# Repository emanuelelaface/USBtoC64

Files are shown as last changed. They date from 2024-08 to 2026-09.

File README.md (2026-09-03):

# USB Adapter for Commodore 64, AMIGA and ATARI Joystick and Mouse Port

This adapter interfaces a USB device with the CONTROL Port of the C64, AMIGA and ATARI, allowing it to be used as a mouse or joystick.

The joystick connects via pins 1, 2, 3, 4, and 6 of the CONTROL port, with the GPIOs simply set as open circuits or shorted to ground when a joystick direction is pressed.

On the C64, the mouse uses the analog part of the port (Pot X and Pot Y). The Commodore 64 has these two pins for evaluating an analog resistor that charges an internal capacitor. The charging time is decoded as a resistor value with a digital value from 0 to 255. The trick used by Commodore engineers to use it as a mouse was to send a pulse at the right moment, making the C64 believe that the capacitor is fully charged. To establish the right moment, the C64 goes through 512 cycles (almost 512 microseconds, since the clock frequencies of PAL and NTSC are not exactly 1 MHz: PAL is 0.985248 MHz, NTSC is 1.022727 MHz). During the first 256 cycles, the potentiometer is set to ground, then it charges the capacitor.

The idea is to use an ESP32 board to wait for the discharge drop and then an additional 256 cycles, finally sending the proper value to the C64 at the right moment. The ESP32 allows interrupts when an input signal is falling; however, the voltage from the C64 is a bit too low for the ESP32 interrupt because the board requires at least 3 volts, while the C64 provides around 1.2 volts. Therefore, a BJT is used to amplify the signal (and invert it, so it is HIGH when the C64 is LOW, which reduces noise in detecting the status).

The initial variable values are the timing for a PAL C64 and are obtained empirically. The NTSC version of the timings are calculated scaling for the ratio of the frequencies NTSC/PAL. It is possible that another C64 may use slightly different timing, though it should be quite stable since Commodore sold the same mouse to everyone. When I will have one NTSC Commodore, I will test it and adjust the timings if needed.

On AMIGA and ATARI the mouse is encoded in the quadrature signal using two trains of pulses with 90 degrees of shift in order to identify the steps and the directions of the motion.

There is an additional switch to make the board work in mouse mode or joystick mode. In mouse mode, any connected device will use the analog mouse, so a program like GEOS can be controlled with a USB mouse or a gamepad. In joystick mode, the board uses the joystick pins for any kind of device. This means that some games, like graphic adventure games (e.g., Maniac Mansion), can be played with a mouse even if they were originally designed for a game controller.

The target computer selection (C64 / AMIGA / ATARI) is user-selectable and stored in non-volatile memory, so it persists across reboots. To change it you must connect a USB mouse to the adapter, turn on the computer and, within the first 30 seconds from the boot, press and hold one mouse button for about 5 seconds until the LED blinks. The button you hold selects the target machine:
- **Left button**: Commodore 64
- **Right button**: AMIGA
- **Middle button**: ATARI

After the LED blink feedback, the adapter reboots and returns to the normal LED behavior (mouse mode or joystick mode depending on the switch position).

The PCB are in two versions: THT (version 3.2) and SMD (version 4.1). The functionalities are identical.

<p align="center">
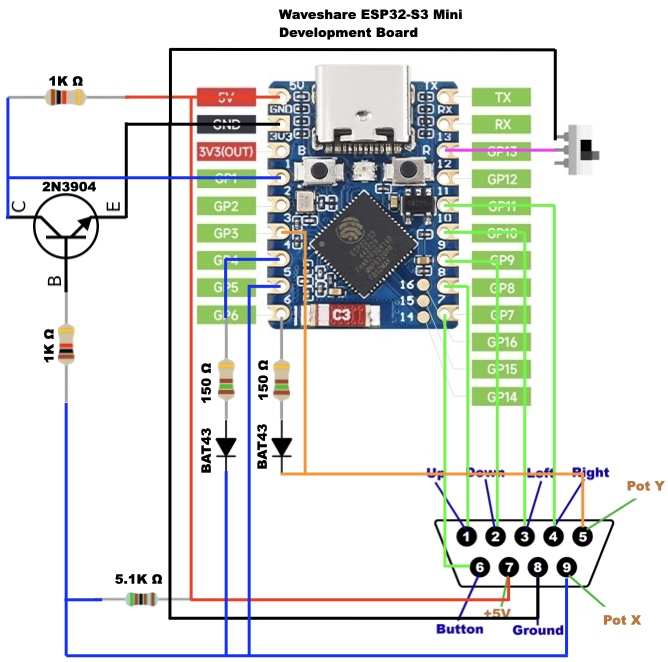
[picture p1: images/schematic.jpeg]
Schematic
  
</p>

<div style="display: flex; justify-content: space-between;">
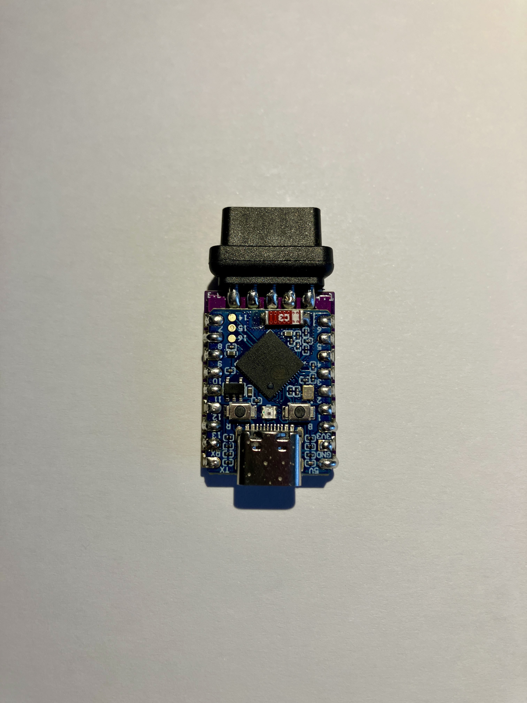
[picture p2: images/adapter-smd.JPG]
SMD
  
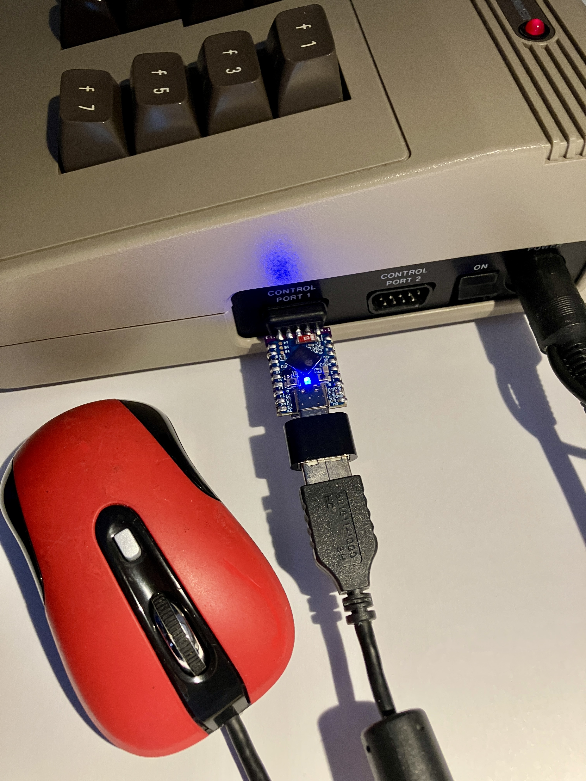
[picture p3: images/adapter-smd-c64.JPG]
SMD C64
  
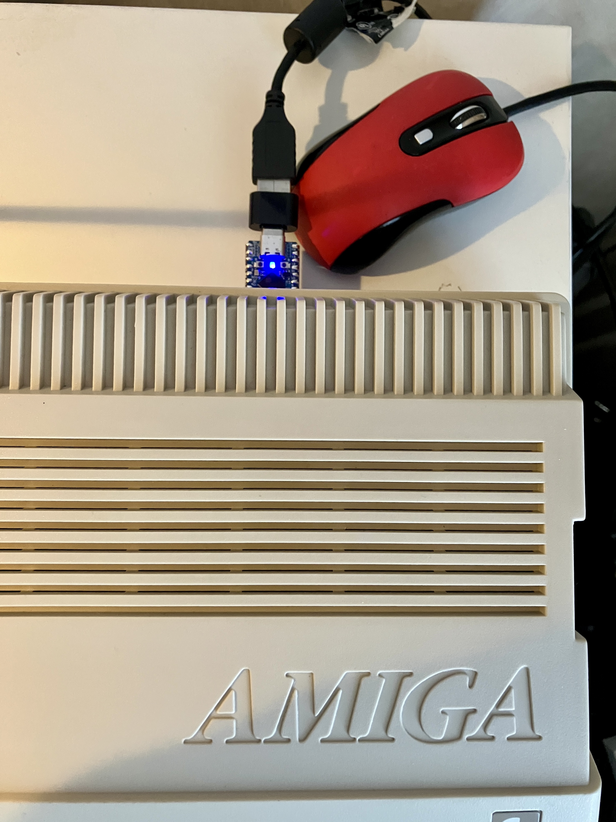
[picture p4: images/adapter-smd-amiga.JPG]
SMD Amiga
  
</div>

<div style="display: flex; justify-content: space-between;">
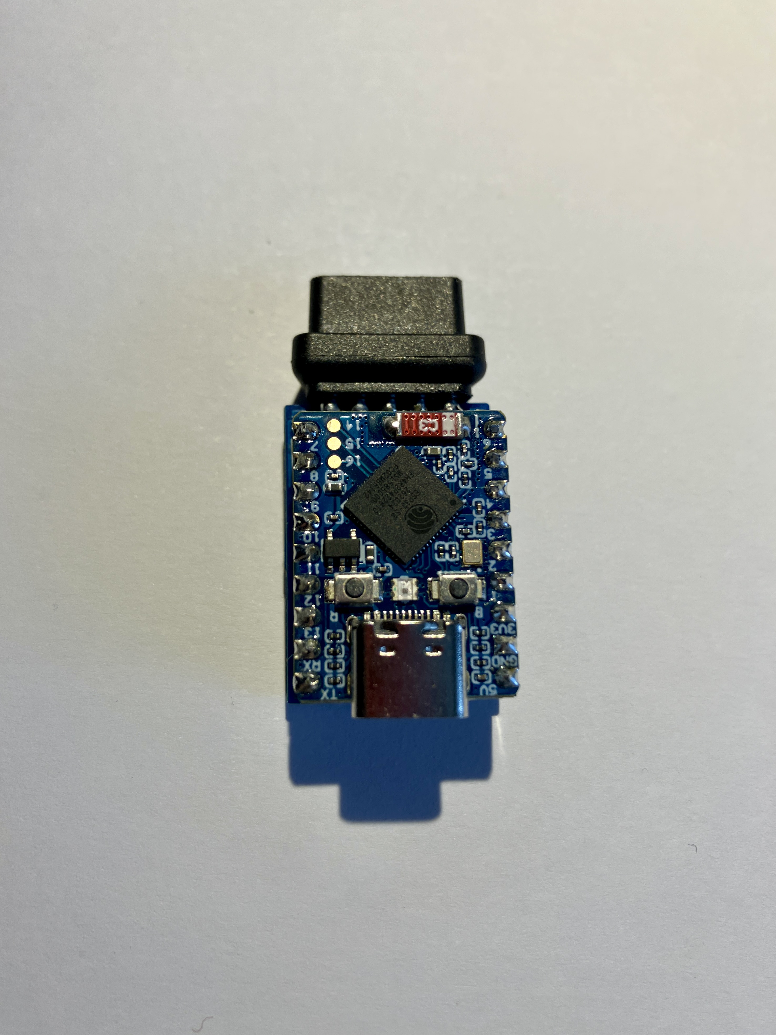
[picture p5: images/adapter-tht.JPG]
THT
  
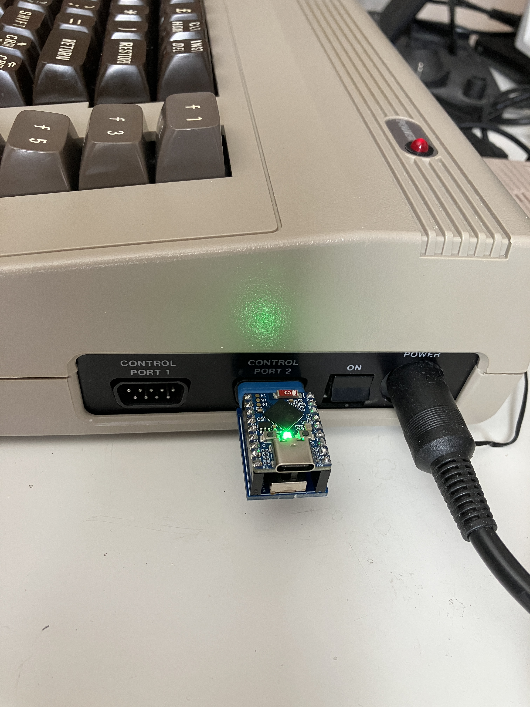
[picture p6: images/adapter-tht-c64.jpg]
THT C64
  
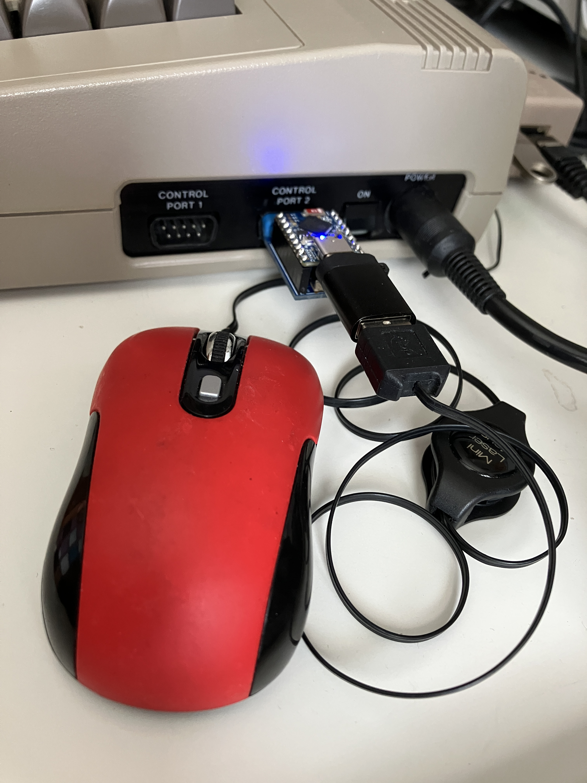
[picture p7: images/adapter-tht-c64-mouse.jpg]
THT C64 Mouse
  
</div>

## Pre-assembled and Tested Board

<div style="display: flex; justify-content: space-between;">
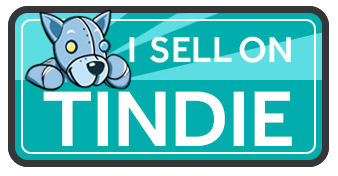
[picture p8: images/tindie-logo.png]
Tindie Logo Link
  
</div>

If you like this project and want a fully assembled and tested board, you can purchase it on [Tindie](https://www.tindie.com/products/burglar_ot/usb-to-commodore-64-amiga-atari/). By doing so, you can also benefit from a customized configuration and support the future development of the project.

## Components

- **ESP32 S3 Mini**: I use the [Waveshare](https://www.waveshare.com/esp32-s3-zero.htm) version. There are other boards with a similar form factor, but the pinout may be different, which would require redesigning the board.
- **2N3904 NPN transistor**.
- **PCB Slide Switch, 3-pin**.
- **Two 1 kOhm resistors, 1% tolerance**.
- **Two 150 Ohm resistors, 1% tolerance**.
- **One 5.1 kOhm resistor, 1% tolerance**.
- **Two BAT 43 Schottky Diodes**.
- **DE-9 (also known as D-SUB 9 or DB 9) female connector**: It's good practice to remove the metallic enclosure because it can easily short the +5V line of the C64 when inserted, potentially damaging your computer.

---

## Installation From Arduino IDE

To install the code from the source file **USBtoC64.ino**, you will need the Arduino IDE. Ensure that the ESP32 board is installed, specifically the ESP32S3 Dev Module.  
The flag `PAL` is for C64 PAL / NTSC selection.

Additionally, the ESP32 USB HID HOST library is required. This library is not available in the official repository. You can download the ZIP file of the repository from [ESP32_USB_Host_HID](https://github.com/esp32beans/ESP32_USB_Host_HID). To install it, go to `Sketch -> Include Library -> Add .ZIP Library` in the Arduino IDE.

To set the board in upload mode, hold the **BOOT** button while the board is disconnected from the USB port. Then, connect the board to the USB port and after one second, the USB port should appear in the list of ports in the Arduino IDE. You can then upload the code.

To select PAL or NTSC timing the `#define PAL` line has to be set as true or false.

## Installation From the Binary File

Alternatively, you can load the binary file **USBtoC64-AMIGA-ATARI-PAL.bin** or **USBtoC64-AMIGA-ATARI-NTSC.bin**, which are located in the `BIN` folder.
The tool to upload the binary is `esptool`. This is available as a web page or as python. The web page should be compatible with Chrome browser or similar, probably not with Firefox, but on some operating system (like Mac OS) there can be a problem of binding the port to the web page. Anyway my suggestion is to try the web page first because it is very fast, and if it does not work try with the python installation.

### From the web page

1. Disconnect the adapter from the Commodore 64 / AMIGA / ATARI.
2. Press and hold the **BOOT** button before connecting the board to the USB cable on the computer. Then, connect the board, wait a second, and release the button.
3. Go to the [esptool](https://espressif.github.io/esptool-js/) website, click on **Connect**, select the port for your adapter, change the Flash Address into `0x0000` and upload the firmware.

### From Python

1. Install the esptool with `pip install esptool`.
2. Disconnect the adapter from the Commodore 64.
3. Press and hold the **BOOT** button before connecting the board to the USB cable on the computer. Then, connect the board, wait a second, and release the button.
4. On the computer, run:

   `esptool.py -b 921600 -c esp32s3 -p <PORT> write_flash --flash_freq 80m 0x00000 USBtoC64-<PAL|NTSC>.bin`

   where `<PORT>` is the USB port created once the board is connected. On Windows, it is probably COM3 or something similar. On Linux and Mac, it will be `/dev/tty.USBsomething` or `/dev/cu.usbsomething`. `<PAL|NTSC>` is the version with the timings for PAL or for NTSC version of the Commodore 64.

---

## Joystick Configuration

Each joystick or gamepad presents data to the USB in a different way. The library used for ESP32 receives an array of `uint8_t` where each element of the array is connected to a button or an axis, and it is not possible to predict in advance how the joystick will associate this data to the buttons. Therefore, the user has to configure the USBtoC64 manually. To do this, follow the procedure below:

- Identify the **BOOT** button on the board. It is the left button when the USB port is oriented towards the top.
- Disconnect the joystick from the controller.
- When the controller is connected to the Commodore 64, it will boot with a `RED` LED for one second, then it will change to green (for Joystick) or blue (for mouse) depending on the position of the switch mode.
- To set the controller in configuration mode, the **BOOT** button must be pressed during the red light. This can be done by rebooting the board (pressing the other button on the board, which is the reset button) and then holding the **BOOT** button during the red LED.
- If pressed correctly, the red light will flash 10 times quickly, and then a `GREEN` LED will indicate that the board is in configuration mode.
- Insert the USB controller to configure; the green light should turn off, and the controller is ready to be programmed.
- The procedure now requires the insertion of 7 controls: the 4 directions in the exact sequence **UP, DOWN, LEFT, RIGHT**, and then 3 buttons for **FIRE**. (3 because most controllers have many buttons and it can be useful to map more than one to fire. Additionally, when the joystick is used in mouse mode, the first 2 fire buttons are assigned as left and right buttons.)
- To associate the controls, press the **BOOT** button each time and then the controller direction.
- Press the **BOOT** button; a `BLUE` LED should appear, and the controller will wait for the UP direction. Once the UP direction is pressed on the controller, the blue LED will turn off.
- Repeat the previous step for DOWN, LEFT, RIGHT, FIRE1, FIRE2, FIRE3.
- After the last button, the controller will flash a `GREEN` LED and will be set to work with that controller.
- It is now possible to reboot the controller and use it with the configured joystick.

If your controller is advanced, with analog joystick and you want to map specifically as mouse or you want some more advanced customization you can discover how your values are mapped following this [Configurator](https://raw.githack.com/emanuelelaface/USBtoC64/main/configurator/config.html) (it works on Chrome and similar browsers, not on Firefox) and once you download the JoystickMapping file you can contact me for a specific configuration, or if you know your business you can code your controls directly in the firmware source replacing the example JoystickMapping.h file and upload to your controller.

---

## Mouse Wheel Support (C64OS + AmigaOS)

An additional **MouseMapping.h** is available to support the **mouse wheel (scroll)** on both **C64OS** and **AmigaOS**.
In order to activate it in the code the variable **MOUSE_MAP_CUSTOM** must be set to **1** and the proper mouse mapping has to be added in the **MM_REPORT_MAPS**. This requires to know how the bytes of the mouse are mapped, I am working on a procedure to get this authomatically in the future.

### C64OS (Wheel Support)
- Requires **C64OS version 1.03 or newer**.
- In the **Mouse** settings/menu, select the **Micromys** driver.

### AmigaOS (Wheel Support)
- Install [FreeWheel](https://aminet.net/package/util/mouse/FreeWheel) on your Amiga.
- Open **FreeWheel** settings, go to **Set Buttons**, and set the **Middle button** to enable scrolling.

---

WARNING: Some controllers may use the USB port to charge a battery (especially if they are also Bluetooth), and this could draw more than 100 mA from the C64, potentially shutting down the Commodore (and possibly damaging it). If you use a controller with a battery, you should remove the battery before connecting it or disable the charging functionality if possible.

---

WARNING: DON'T CONNECT THE COMMODORE 64 AND THE USB PORT TO A SOURCE OF POWER AT THE SAME TIME.  
THE POWER WILL ARRIVE DIRECTLY TO THE SID OF THE COMMODORE AND MAY DESTROY IT.

---

THE SOFTWARE IS PROVIDED “AS IS”, WITHOUT WARRANTY OF ANY KIND, EXPRESS OR IMPLIED, INCLUDING BUT NOT LIMITED TO THE WARRANTIES OF MERCHANTABILITY, FITNESS FOR A PARTICULAR PURPOSE AND NONINFRINGEMENT. IN NO EVENT SHALL THE AUTHORS OR COPYRIGHT HOLDERS BE LIABLE FOR ANY CLAIM, DAMAGES OR OTHER LIABILITY, WHETHER IN AN ACTION OF CONTRACT, TORT OR OTHERWISE, ARISING FROM, OUT OF OR IN CONNECTION WITH THE SOFTWARE OR THE USE OR OTHER DEALINGS IN THE SOFTWARE.

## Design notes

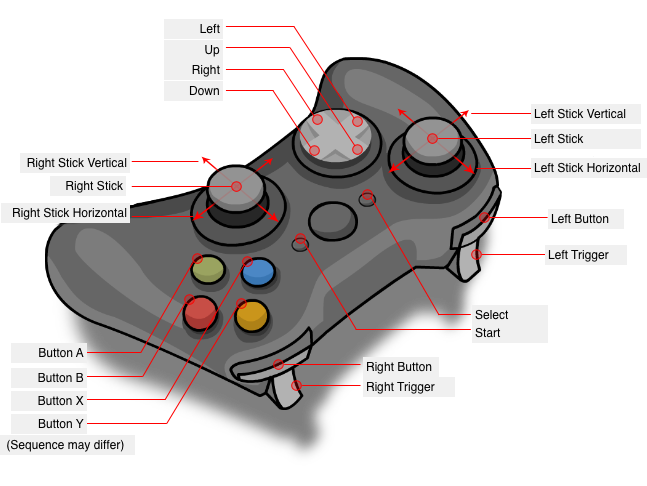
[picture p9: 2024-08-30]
images/gamepad.png

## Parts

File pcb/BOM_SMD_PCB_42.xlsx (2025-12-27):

Designator | Footprint | JLCPCB Part # | Quantity | Description | Manufacturer | Comment | Value
D1 | 2N3904 | C18536 | 1 | 100@10mA,1V 200mA 300MHz 300mV 350mW 40V NPN SOT-23 Bipolar (BJT) ROHS | KEC Semicon | NPN transistor
D2 | PCB Slide Switch, 3-pin | C259308 | 1 | -25℃~+80℃ 1.5mm 10,000 Cycles 300mA 3mm 6V 7mm Black Gull Wing Rectangular Columnar SPDT Surface Mount, Right Angle SMD,7x3mm Slide Switches ROHS | Korean Hroparts Elec
D3,D4 | 1 kOhm resistors | C17513 | 2 | -55℃~+155℃ 125mW 150V 1kΩ Thick Film Resistor ±1% ±100ppm/℃ 0805 Chip Resistor - Surface Mount ROHS | UNI-ROYAL(Uniroyal Elec)
D5,D6 | 150 Ohm resistors | C17471 | 2 | -55℃~+155℃ 125mW 150V 150Ω Thick Film Resistor ±1% ±100ppm/℃ 0805 Chip Resistor - Surface Mount ROHS | UNI-ROYAL(Uniroyal Elec)
D7 | 5.1 kOhm resistor | C26023 | 1 | -55℃~+155℃ 125mW 150V 5.1kΩ Thick Film Resistor ±100ppm/℃ ±5% 0805 Chip Resistor - Surface Mount ROHS | UNI-ROYAL(Uniroyal Elec)
D8,D9 | BAT 43 Schottky Diodes | C22466358 | 2 | -40℃~+125℃ 200mA 30V 450mV@15mA 4A 500nA@25V Independent SOD-123 Schottky Diodes ROHS | hongjiacheng

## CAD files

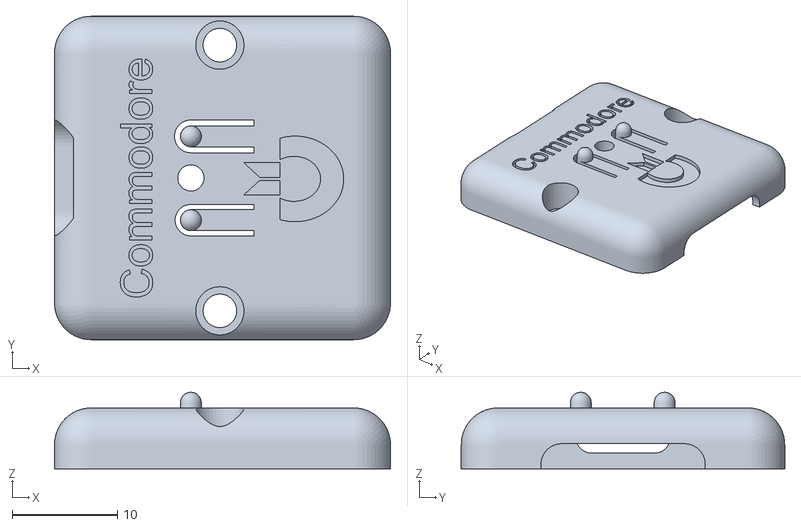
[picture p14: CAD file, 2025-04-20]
3Dcase/SMD/top.stl
32.0 x 30.8 x 7.30

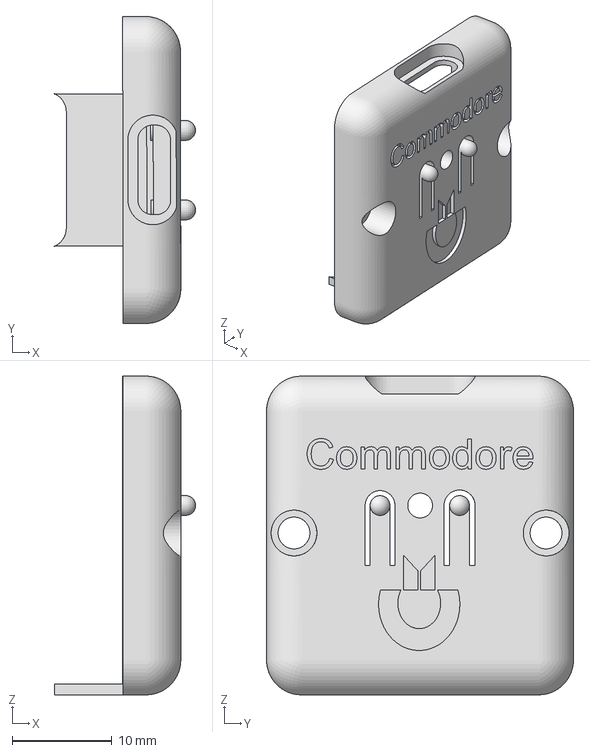
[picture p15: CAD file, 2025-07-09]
3Dcase/THT/top.3mf
14.2 x 30.8 x 32.0 mm

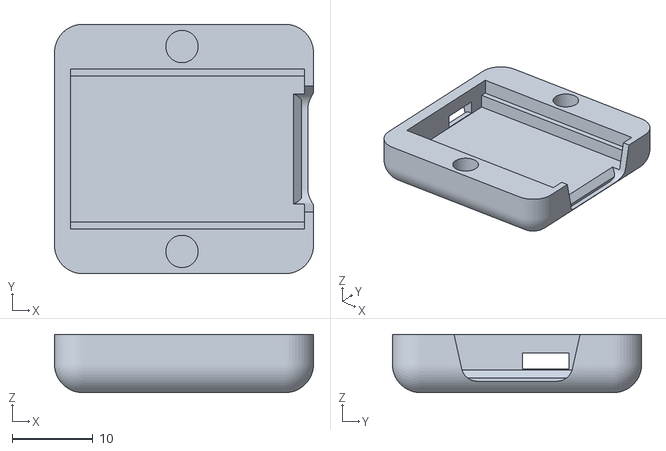
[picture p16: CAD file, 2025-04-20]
3Dcase/SMD/bottom.stl
32.0 x 30.8 x 7.20

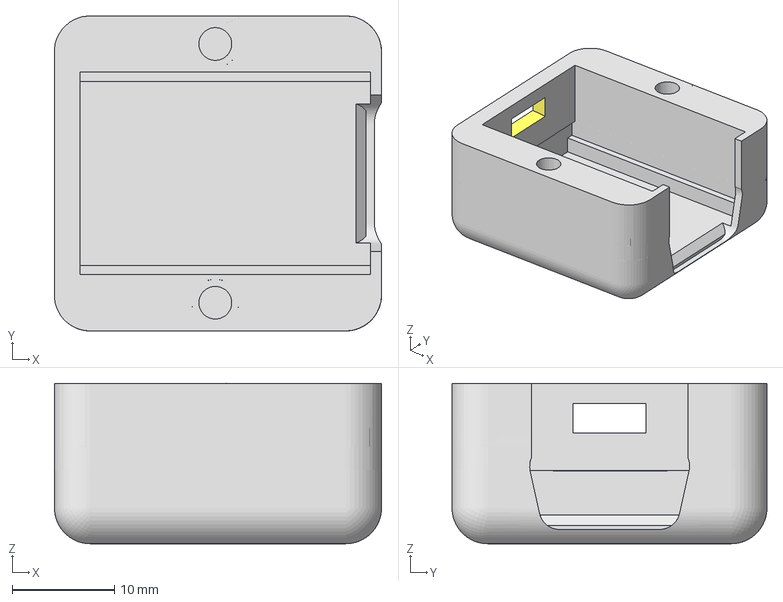
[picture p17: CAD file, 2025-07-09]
3Dcase/THT/bottom.3mf
32.0 x 30.8 x 15.7 mm

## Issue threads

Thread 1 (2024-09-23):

Never leaves configuration mode.

chris-edwards-pub, 2024-09-23:
I booted into configuration mode, then insert mouses USB and the green light just stays on.  Never turns off.  Any ideas?

emanuelelaface, 2024-09-23:
hi, so if I understood correctly, you started the board, when there is the red light you hold the B button, the red led flashes and then you have the green led on. Now you insert the USB joystick/gamepad and nothing happens, am I right?

chris-edwards-pub, 2024-09-23:
Thanks!  I was trying to configure the mouse.  BTW, the mouse work perfect.

emanuelelaface, 2024-09-23:
perfect, thanks for the check!

Closed 2024-09-23.

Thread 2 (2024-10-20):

Mouse not recognized using BackSID

doughamm, 2024-10-20:
Using a BackSID, the pots won't register. BackSID is one of the few SID replacements that emulates pots but others that do may have problems as well.  BackSID works with MouSTer just fine but not USBtoC64.

emanuelelaface, 2024-10-20:
Hi, at the time I developed this device I had a C64 with an original SID that produces the timing signal for the POTS all the time, and I created the project around that. Then a user reported the issue with ARMSID and I discovered that those clones do not generate the signal unless there is some voltage applied to the pot. So I fixed the design but I still have few adaptors from the previous design that are compatible only with the original SID. This is why on the site where I sell them I ask specifically to say if the user wants to use with a clone SID in order to send a modified version that is compatible with it.

By the way, I tested it with ARMSID and SIDKick, not with BackSID (I do not have one) but I guess it will work also with it because I think the only problem is to enable the digital generation of the signal on the POT pins.

Said this, please contact me on the place where you bought the adapter and I will try to fix this issue for you.

doughamm, 2024-10-20:
Ah, I totally see now this option on the Tindy site that either didn't exist or I hadn't noticed back in September when I ordered!

https://www.tindie.com/products/burglar_ot/usbtoc64/

About half my systems are BackSID while the rest are authentic; does the revised board retain compatibility with authentic SIDs or do you essentially need a board for each scenario?

In any case I would love to acquire the revised one. Happy to do so however is most convenient.

Thank you!

emanuelelaface, 2024-10-20:
Yes the other revision works with every system, but maybe you can modify your without order a new one. I will write you from Whatsapp if you don't mind, on the number provided on Tindie.

doughamm, 2024-10-26:
Just updating the issues log to echo my WhatsApp discussion for the greater community: adding a resistor gets it to recognize a mouse on the BackSID, and it does move, but it's unusably jumpy (whether a mouse is connected or not).  I've also let Evie know on her forum since this may be a firmware-solvable issue as much as a hardware one: https://forum.backbit.io/index.php?topic=1218.0

emanuelelaface, 2024-11-22:
I will close here. I think the issue with BackSID is possibly due to the voltage expected buy the replacement SID or something else. I cannot test it in my lab because I do not have one and to do a full debug I need to see the signals with an oscilloscope. I had the possibility to test it with ARMSID and SIDKick, both work fine, but BackSID probably needs +5v as HIGH signal while the ESP32 board uses +3.3v.

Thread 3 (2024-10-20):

Gamepad compatibility list?

doughamm, 2024-10-20:
Unsure if this should be here, but it would be useful to know what pads and sticks are tested as working and which should not be used for safety reasons. Thanks!

emanuelelaface, 2024-10-20:
I am not sure that it is an issue, but it is fine to have it here.
So far the gamepad used by the users are many and some of them is not even commercial but custom made and all of them worked fine. For some of them I had to create a specific firmware, but none of them had issues with the commodore.
My disclaimer is because I discovered that the 8bitdo pro 2 (my controller) charges the battery from the USB and this absorbs more power than the one provided by the Commodore, and when this happens the Commodore shuts down (probably not very healthy). The problem is easily fixable removing the battery from the controller when used with the C64.

Any other controller (I had reports from dozens of users) are perfectly fine, even for non-commercial devices.
If you have a specific controller that you want to use you may try to contact me directly (from the site where you bought it) and I can help you with a custom firmware for your game controller, or I can check if some other user reported it as safe (but I am quite sure that it is most of the time).

doughamm, 2024-10-20:
Thank you! I attempted to try an Xbox One controller over micro USB seeing as it has no battery and would be safe. Didn't seem to work, but I'll give it another shot if you suggest it ought to be compatible. Sometimes you grab a power-only cable meaning to use a data cable.

emanuelelaface, 2024-10-20:
It should work, but I suggest you to contact me anyway.

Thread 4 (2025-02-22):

Slide switch used for SMD version?

mamejay, 2025-02-22:
Hi there.
Just discovered this device and wanted to make a small batch for myself.
Just wondering what slide switch is used.  Would it be possible to post a link to what you have used?

Thanks!

emanuelelaface, 2025-02-22:
Sure, which PCB you want to assemble, the SMD or the THT?

mamejay, 2025-02-23:
SMD

mamejay, 2025-02-23:
@emanuelelaface I think I found it.
https://www.lcsc.com/product-detail/Slide-Switches_SHOU-HAN-MINI-MSK12CO2_C2681570.html?s_z=n_spdt
This looks to be the same footprint I can see in the gerber

emanuelelaface, 2025-02-23:
The one you posted seems the correct one. I use this:

https://www.aliexpress.com/item/32950410769.html?spm=a2g0o.order_list.order_list_main.89.15391802l30khy

mamejay, 2025-02-23:
Superstar!  Thank you.  Will buy a few boards when I place my next PCB order

emanuelelaface, 2025-02-23:
Perfect. Feel free to contact me for specific customizations or in case of some issue that blocks you from having it working.

Closed 2025-02-23.

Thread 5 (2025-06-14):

Diagonal key use

DExUS5, 2025-06-14:
Hi,

thanks for the device & code, it's a life saver if you don't have any joysticks around.
I have one question, does it support diagonal key use?  (LEFT+UP / DOWN , RIGHT + UP / DOWN)  ?
I'm asking because it doesn't work on my gamepad and I'm not sure if this device has the functionality. (using on C64)

Closed 2025-06-14.

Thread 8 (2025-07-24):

Support for 2.4GHz wireless mice?

rtlemon, 2025-07-24:
There's a nice project to convert a Logitech m185 to tank like mouse (https://www.printables.com/model/1137373-amiga-mouse-logitech-m185) and I was wondering is this adapter works with wireless dongles.

emanuelelaface, 2025-07-24:
In general yes, the only problem can be if the dongle uses to much current or if it is an USB HUB (some dongle supports mouse and keyboard so it presents as HUB).

rtlemon, 2025-09-06:
Just finished making one and I can confirm that it works great with the 2.4GHz wireless dongle.

Closed 2025-09-07.

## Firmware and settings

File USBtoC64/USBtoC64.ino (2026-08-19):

/*
USB to Commodore 64, AMIGA and ATARI adaptor V 4.1 by Emanuele Laface

WARNING: DON'T CONNECT THE COMMODORE 64 AND THE USB PORT TO A SOURCE OF POWER AT THE SAME TIME.
THE POWER WILL ARRIVE DIRECTLY TO THE SID OF THE COMMODORE AND MAY DESTROY IT.

---

THE SOFTWARE IS PROVIDED “AS IS”, WITHOUT WARRANTY OF ANY KIND, EXPRESS OR IMPLIED,
INCLUDING BUT NOT LIMITED TO THE WARRANTIES OF MERCHANTABILITY, FITNESS FOR A PARTICULAR
PURPOSE AND NONINFRINGEMENT. IN NO EVENT SHALL THE AUTHORS OR COPYRIGHT HOLDERS BE LIABLE
FOR ANY CLAIM, DAMAGES OR OTHER LIABILITY, WHETHER IN AN ACTION OF CONTRACT, TORT OR OTHERWISE,
ARISING FROM, OUT OF OR IN CONNECTION WITH THE SOFTWARE OR THE USE OR OTHER DEALINGS IN THE SOFTWARE.
*/

#include "driver/gpio.h"
#include "soc/gpio_struct.h"
#include "usb/usb_host.h"
#include "hid_host.h"
#include "hid_usage_mouse.h"
#include "esp_log_buffer.h"
#include "esp_timer.h"
#include "Adafruit_NeoPixel.h"
#include "EEPROM.h"
#include "freertos/FreeRTOS.h"
#include "freertos/task.h"

#include "JoystickMapping.h"
#include "MouseMapping.h"

#define PIN_WS2812B       21 // Pin for RGB LED
#define NUM_PIXELS         1 // 1 LED
Adafruit_NeoPixel ws2812b(NUM_PIXELS, PIN_WS2812B, NEO_RGB + NEO_KHZ800); // Keep NEO_RGB (project convention)

// LED color helpers (keep the original project channel convention)
// With NEO_RGB on typical WS2812, R and G appear swapped in this project:
// - green as Color(25,0,0)
// - red   as Color(0,25,0)
// - blue  as Color(0,0,25)
static inline uint32_t LED_BLUE()  { return ws2812b.Color(0, 0, 25); }
static inline uint32_t LED_GREEN() { return ws2812b.Color(25, 0, 0); }
static inline uint32_t LED_RED()   { return ws2812b.Color(0, 25, 0); }

// Define GPIOs for C64
#define C64_FIRE           7
#define C64_UP             8
#define C64_DOWN           9
#define C64_LEFT          10
#define C64_RIGHT         11
#define C64_POTX           4
#define C64_POTY           6
// Define GPIO for interrupt from C64
#define C64_INT            1
// Define GPIO for switch Mouse - Joystick
#define SWITCH_MJ         13 // HIGH = mouse, LOW = joystick

// Define the default timers for the mouse delay, all empirical for PAL version
#define PAL                0 // Select if it is PAL or NTSC and adjust the timings

#if PAL
  #define MINdelayOnX   2450
  #define MAXdelayOnX   5040
  #define MINdelayOnY   2440
  #define MAXdelayOnY   5100
  #define STEPdelayOnX    10.16689245
  #define STEPdelayOnY    10.14384171
  // Define the timing for mouse used as Joystick
  #define M2JCalib       833 // 20000 at 240 MHz
#else
  #define MINdelayOnX   2360
  #define MAXdelayOnX   4855
  #define MINdelayOnY   2351
  #define MAXdelayOnY   4913
  #define STEPdelayOnX     9.794315054
  #define STEPdelayOnY     9.772109035
  // Define the timing for mouse used as Joystick
  #define M2JCalib      802 // 20000 at 240 MHz
#endif

#define A_FIRE            7
#define A_UP              8
#define A_DOWN            9
#define A_LEFT           10
#define A_RIGHT          11
#define A_BUTTON2         5
#define A_BUTTON3         3
#define PULSE_LENGTH    150 // Length of pulse for Amiga mouse

#define CONFIG            0 // Set the configuration switch to the "Boot" button
#define JOYBUTTONS        7 // 4 directions and 3 fire

// EEPROM layout: first JOYBUTTONS*2 bytes are joystick mapping (original),
// then 2 bytes are reserved for the target mode selection
#define EEPROM_MODE_MAGIC_ADDR   (JOYBUTTONS * 2)
#define EEPROM_MODE_VALUE_ADDR   (JOYBUTTONS * 2 + 1)
#define EEPROM_MODE_MAGIC        0xA5
#define EEPROM_SIZE              (JOYBUTTONS * 2 + 2)

// Target modes selectable by the user with a 5 seconds mouse button hold
#define MODE_C64   0
#define MODE_AMIGA 1
#define MODE_ATARI 2

uint8_t gMode = MODE_C64;

// Keep original flags, but they are forced from gMode
int ISC64 = 0;
int ISAMIGA = 1;

uint8_t H[4]  = { LOW, LOW, HIGH, HIGH };
uint8_t HQ[4] = { LOW, HIGH, HIGH, LOW };

uint8_t QX = 3;
uint8_t QY = 3;

// Define the volatile variables for the hardware timers
volatile uint64_t delayOnX = MINdelayOnX;
volatile uint64_t delayOnY = MINdelayOnY;
volatile uint64_t delayOffX = 10;
volatile uint64_t delayOffY = 10;

// Define the hardware timers
hw_timer_t *timerOnX = NULL;
hw_timer_t *timerOnY = NULL;
hw_timer_t *timerOffX = NULL;
hw_timer_t *timerOffY = NULL;

// Variables used to configure the board for the joystick connected
bool configMode = false;
uint8_t defaultConfigData[100];
int defaultConfigLength = 0;

// These two in particular use the configuration to match the usage of the controller
uint8_t joyVal[JOYBUTTONS];
uint8_t joyPos[JOYBUTTONS];

// -------------------- Mode switching by mouse hold --------------------
static esp_timer_handle_t modeHoldTimer = NULL;
static volatile uint8_t modeHoldMask = 0;      // 0x01 left, 0x02 right, 0x04 middle
static volatile uint8_t modeHoldTarget = MODE_C64;
static volatile bool modeHoldArmed = false;
static volatile bool modeSwitchInProgress = false;

// ---- NEW: allow mode switching only in the first 30 seconds after boot ----
#define MODE_SWITCH_WINDOW_US (30LL * 1000000LL)   // 30 seconds
static int64_t gModeSwitchDeadlineUs = 0;
static volatile bool gModeSwitchEnabled = true;

static inline void clearModeHoldState() {
  modeHoldArmed = false;
  modeHoldMask = 0;
}

// Checks if mode switching is still allowed (and permanently disables it after the window)
static inline bool modeSwitchAllowedNow() {
  if (!gModeSwitchEnabled) return false;

  if (esp_timer_get_time() > gModeSwitchDeadlineUs) {
    // Window expired: lock permanently
    gModeSwitchEnabled = false;

    // Stop any pending hold
    if (modeHoldTimer) esp_timer_stop(modeHoldTimer);
    clearModeHoldState();

    return false;
  }
  return true;
}

static void setRuntimeLed() {
  // Runtime behavior: mouse = blue, joystick = green
  if (digitalRead(SWITCH_MJ)) ws2812b.setPixelColor(0, LED_BLUE());
  else                        ws2812b.setPixelColor(0, LED_GREEN());
  ws2812b.show();
}

static void blinkModeLed(uint8_t mode) {
  uint32_t c = LED_BLUE();               // C64
  if (mode == MODE_AMIGA) c = LED_GREEN();
  if (mode == MODE_ATARI) c = LED_RED();

  for (int i = 0; i < 3; i++) {
    ws2812b.clear();
    ws2812b.show();
    delay(120);
    ws2812b.setPixelColor(0, c);
    ws2812b.show();
    delay(120);
  }
  ws2812b.clear();
  ws2812b.show();
}

static uint8_t loadModeFromEEPROM() {
  uint8_t magic = EEPROM.read(EEPROM_MODE_MAGIC_ADDR);
  uint8_t mode  = EEPROM.read(EEPROM_MODE_VALUE_ADDR);

  if (magic != EEPROM_MODE_MAGIC || mode > MODE_ATARI) {
    // Default mode on first boot: C64
    mode = MODE_C64;
    EEPROM.write(EEPROM_MODE_MAGIC_ADDR, EEPROM_MODE_MAGIC);
    EEPROM.write(EEPROM_MODE_VALUE_ADDR, mode);
    EEPROM.commit();
  }
  return mode;
}

static void saveModeToEEPROM(uint8_t mode) {
  EEPROM.write(EEPROM_MODE_MAGIC_ADDR, EEPROM_MODE_MAGIC);
  EEPROM.write(EEPROM_MODE_VALUE_ADDR, mode);
  EEPROM.commit();
}

static void applyModeToOriginalFlags() {
  if (gMode == MODE_C64) {
    ISC64 = 10;      // Force the original "C64 path"
    ISAMIGA = 1;     // Irrelevant in C64 path
  } else {
    ISC64 = 0;       // Force the original "AMIGA/ATARI path"
    ISAMIGA = (gMode == MODE_AMIGA) ? 1 : 0;
  }
}

static void requestModeChange(uint8_t newMode) {
  // NEW: also enforce the 30s window here (covers edge-case scheduling)
  if (!modeSwitchAllowedNow()) { modeSwitchInProgress = false; return; }

  if (newMode > MODE_ATARI) { modeSwitchInProgress = false; return; }
  if (newMode == gMode)     { modeSwitchInProgress = false; clearModeHoldState(); return; }

  gMode = newMode;
  saveModeToEEPROM(gMode);

  // Visual feedback: 3 blinks with selected mode color, then return to runtime color
  blinkModeLed(gMode);
  setRuntimeLed();

  // Reboot to re-init pins/timers/USB in a clean state
  esp_restart();
}

static void modeSwitchTask(void *arg) {
  // NEW: double-check window in task context too
  if (!modeSwitchAllowedNow()) {
    modeSwitchInProgress = false;
    clearModeHoldState();
    vTaskDelete(NULL);
  }

  uint8_t mode = (uint8_t)(uintptr_t)arg;
  requestModeChange(mode);
  vTaskDelete(NULL);
}

static void modeHoldTimerCb(void *arg) {
  (void)arg;

  // NEW: if window expired, do nothing
  if (!modeSwitchAllowedNow()) { modeSwitchInProgress = false; return; }

  if (modeSwitchInProgress) return;
  if (!modeHoldArmed) return;

  uint8_t m = modeHoldMask;
  if (!(m == 0x01 || m == 0x02 || m == 0x04)) { clearModeHoldState(); return; }

  uint8_t target = modeHoldTarget;

  if (target == gMode) {
    clearModeHoldState();
    modeSwitchInProgress = false;
    return;
  }

  if (!((m == 0x01 && target == MODE_C64) ||
        (m == 0x02 && target == MODE_AMIGA) ||
        (m == 0x04 && target == MODE_ATARI))) {
    clearModeHoldState();
    return;
  }

  modeSwitchInProgress = true;

  BaseType_t ok = xTaskCreatePinnedToCore(
    modeSwitchTask, "mode_switch", 4096, (void*)(uintptr_t)target, 3, NULL, 1
  );

  if (ok != pdPASS) {
    modeSwitchInProgress = false;
    clearModeHoldState();
  }
}

static inline void stopModeHold() {
  if (modeHoldArmed) esp_timer_stop(modeHoldTimer);
  clearModeHoldState();
}

static void updateModeHoldFromMouse(hid_mouse_input_report_boot_t *mouse_report) {
  // NEW: only allow arming/holding in the first 30 seconds after boot
  if (!modeSwitchAllowedNow()) return;

  uint8_t mask = 0;
  if (mouse_report->buttons.button1) mask |= 0x01; // Left
  if (mouse_report->buttons.button2) mask |= 0x02; // Right
  if (mouse_report->buttons.button3) mask |= 0x04; // Middle

  // Only accept exactly one button held
  if (!(mask == 0x01 || mask == 0x02 || mask == 0x04)) {
    stopModeHold();
    return;
  }

  modeHoldMask = mask;

  uint8_t target = MODE_C64;
  if (mask == 0x01) target = MODE_C64;
  else if (mask == 0x02) target = MODE_AMIGA;
  else target = MODE_ATARI;

  // If already armed with same target, do nothing
  if (modeHoldArmed && modeHoldTarget == target) return;

  modeHoldTarget = target;
  modeHoldArmed = true;
  esp_timer_stop(modeHoldTimer);
  esp_timer_start_once(modeHoldTimer, 5000000ULL);
}

// -------------------- USB host plumbing --------------------
static const char *TAG = "USB MESSAGE";
QueueHandle_t hid_host_event_queue;

typedef struct {
  hid_host_device_handle_t hid_device_handle;
  hid_host_driver_event_t event;
  void *arg;
} hid_host_event_queue_t;

static const char *hid_proto_name_str[] = {"NONE", "KEYBOARD", "MOUSE"};

// -------------------- Micromys wheel -> C64 pulses (LEFT/RIGHT lines) --------------------
// Protocol details: pulses active-low, ~50ms low, ~50ms high between pulses.
// We implement non-blocking by using a FreeRTOS task fed by the USB callback.
#define MICROMYS_LOW_MS  50
#define MICROMYS_GAP_MS  50

// If scrolling "up" gives wheel byte 0x01 (and down gives 0xFF), keep 1.
// If it's inverted for your mouse, set to 0.
#define WHEEL_01_IS_UP   1

static TaskHandle_t micromysWheelTaskH = NULL;
static volatile uint16_t mm_up_pending = 0;   // UP pulses  -> C64_LEFT  (bit2)
static volatile uint16_t mm_dn_pending = 0;   // DN pulses  -> C64_RIGHT (bit3)
static portMUX_TYPE mm_mux = portMUX_INITIALIZER_UNLOCKED;

static inline void micromysEnqueueWheel(int8_t wheel)
{
  if (wheel == 0 || micromysWheelTaskH == NULL) return;

  uint16_t steps = (wheel < 0) ? (uint16_t)(-wheel) : (uint16_t)wheel;

#if WHEEL_01_IS_UP
  bool up = (wheel > 0);
#else
  bool up = (wheel < 0);
#endif

  portENTER_CRITICAL(&mm_mux);
  if (up) mm_up_pending += steps;
  else    mm_dn_pending += steps;
  portEXIT_CRITICAL(&mm_mux);

  xTaskNotifyGive(micromysWheelTaskH);
}

static void micromysWheelTask(void *arg)
{
  (void)arg;
  for (;;) {
    ulTaskNotifyTake(pdTRUE, portMAX_DELAY);

    while (true) {
      uint8_t pin = 0;

      portENTER_CRITICAL(&mm_mux);
      if (mm_up_pending) { mm_up_pending--; pin = C64_LEFT; }
      else if (mm_dn_pending) { mm_dn_pending--; pin = C64_RIGHT; }
      portEXIT_CRITICAL(&mm_mux);

      if (pin == 0) break;

      // Active-low pulse
      pinMode(pin, OUTPUT);
      digitalWrite(pin, LOW);
      vTaskDelay(pdMS_TO_TICKS(MICROMYS_LOW_MS));

      // Release line (C64 pull-up brings it to 1)
      digitalWrite(pin, LOW);
      pinMode(pin, INPUT);
      vTaskDelay(pdMS_TO_TICKS(MICROMYS_GAP_MS));
    }
  }
}

// -------------------- Amiga wheel -> "middle button + vertical move" --------------------
#define AMIGA_WHEEL_STEP_Y   30 // Scroll "intensity"
#define AMIGA_WHEEL_INVERT   0 // Scroll direction

static inline int8_t amigaWheelToDeltaY(int8_t wheel)
{
  if (wheel == 0) return 0;

  uint16_t steps = (wheel < 0) ? (uint16_t)(-wheel) : (uint16_t)wheel;
  int16_t delta = (int16_t)steps * (int16_t)AMIGA_WHEEL_STEP_Y;
  if (delta > 127) delta = 127;

#if WHEEL_01_IS_UP
  bool up = (wheel > 0);
#else
  bool up = (wheel < 0);
#endif

#if AMIGA_WHEEL_INVERT
  up = !up;
#endif

  // In a_mouse_m(): y_displacement > 0 => A_Down, y_displacement < 0 => A_Up
  return (int8_t)(up ? -delta : delta);
}

static inline void amigaWheelEmulate(const hid_mouse_input_report_boot_t *base, int8_t wheel)
{
  int8_t y = amigaWheelToDeltaY(wheel);
  if (y == 0) return;

  hid_mouse_input_report_boot_t r = *base;
  r.x_displacement = 0;
  r.y_displacement = 0;
  r.buttons.button3 = 1;
  a_mouse_m(&r);
  delayMicroseconds(25000);
  r.x_displacement = 0;
  r.y_displacement = y;
  r.buttons.button3 = 1;
  a_mouse_m(&r);
  delayMicroseconds(25000);
  r.x_displacement = 0;
  r.y_displacement = 0;
  r.buttons.button3 = 0;
  a_mouse_m(&r);
}

// -------------------- HID callbacks --------------------
static void hid_host_mouse_report_callback(const uint8_t *const data, const int length) {
  
#if (MOUSE_MAP_CUSTOM == 0)
  if (length < (int)sizeof(hid_mouse_input_report_boot_t)) return;
  hid_mouse_input_report_boot_t *mouse_report = (hid_mouse_input_report_boot_t *)data;
  int8_t wheel = 0;
#else
  if (length < 3) return;
  hid_mouse_input_report_boot_t boot;
  int8_t wheel = 0;
  MM_DecodeMouseReport(data, length, &boot, &wheel);
  hid_mouse_input_report_boot_t *mouse_report = &boot;
#endif

  // Micromys wheel support only in C64 + mouse mode:
  if ((ISC64 > 0) && digitalRead(SWITCH_MJ)) {
    micromysEnqueueWheel(wheel);
  }

  updateModeHoldFromMouse(mouse_report);

  if (digitalRead(SWITCH_MJ)) {       // Mouse mode
    if (ISC64 > 0) c64_mouse_m(mouse_report);
    else           a_mouse_m(mouse_report);
  } else {                            // Joystick mode (mouse as joystick)
    if (ISC64 > 0) c64_mouse_j(mouse_report);
    else           a_mouse_j(mouse_report);
  }
  
  // ---- NEW: wheel mapping for AMIGA in mouse mode ----
  if ((ISC64 <= 0) && (ISAMIGA == 1) && digitalRead(SWITCH_MJ) && (wheel != 0)) {
    amigaWheelEmulate(mouse_report, wheel);
  }
}


static void hid_host_generic_report_callback(const uint8_t *const data, const int length) {
#if (JOY_MAPPING_MODE == JOY_MAP_LEARN)
  if (configMode) {
    c64_joystick_config(data, length);
    return;
  }
#endif

  if (digitalRead(SWITCH_MJ)) {       // Mouse mode (joystick as mouse)
    if (ISC64 > 0) c64_joystick_m(data, length);
    else           a_joystick_m(data, length);
  } else {                            // Joystick mode
    if (ISC64 > 0) c64_joystick_j(data, length);
    else           a_joystick_j(data, length);
  }
}

void hid_host_interface_callback(hid_host_device_handle_t hid_device_handle, const hid_host_interface_event_t event, void *arg) {
  uint8_t data[64] = {0};
  size_t data_length = 0;
  hid_host_dev_params_t dev_params;
  ESP_ERROR_CHECK(hid_host_device_get_params(hid_device_handle, &dev_params));

  switch (event) {
    case HID_HOST_INTERFACE_EVENT_INPUT_REPORT:
      ESP_ERROR_CHECK(hid_host_device_get_raw_input_report_data(hid_device_handle, data, 64, &data_length));
      if (HID_SUBCLASS_BOOT_INTERFACE == dev_params.sub_class) {
        if (HID_PROTOCOL_MOUSE == dev_params.proto) {
          hid_host_mouse_report_callback(data, (int)data_length);
        }
      } else {
        hid_host_generic_report_callback(data, (int)data_length);
      }
      break;

    case HID_HOST_INTERFACE_EVENT_DISCONNECTED:
//      ESP_LOGI(TAG, "HID Device, protocol '%s' DISCONNECTED", hid_proto_name_str[dev_params.proto]);
      ESP_ERROR_CHECK(hid_host_device_close(hid_device_handle));
      break;

    case HID_HOST_INTERFACE_EVENT_TRANSFER_ERROR:
//      ESP_LOGI(TAG, "HID Device, protocol '%s' TRANSFER_ERROR", hid_proto_name_str[dev_params.proto]);
      break;

    default:
//      ESP_LOGE(TAG, "HID Device, protocol '%s' Unhandled event", hid_proto_name_str[dev_params.proto]);
      break;
  }
}

void hid_host_device_event(hid_host_device_handle_t hid_device_handle, const hid_host_driver_event_t event, void *arg) {
  hid_host_dev_params_t dev_params;
  ESP_ERROR_CHECK(hid_host_device_get_params(hid_device_handle, &dev_params));
  const hid_host_device_config_t dev_config = {.callback = hid_host_interface_callback, .callback_arg = NULL};

  switch (event) {
    case HID_HOST_DRIVER_EVENT_CONNECTED:
//      ESP_LOGI(TAG, "HID Device, protocol '%s' CONNECTED", hid_proto_name_str[dev_params.proto]);
      ESP_ERROR_CHECK(hid_host_device_open(hid_device_handle, &dev_config));
      if (HID_SUBCLASS_BOOT_INTERFACE == dev_params.sub_class) {

        // Mouse: REPORT (needed for wheel + packed 12-bit XY), or BOOT for compatibility.
        // Keyboard: keep BOOT
        if (HID_PROTOCOL_MOUSE == dev_params.proto) {
#if (MOUSE_MAP_CUSTOM == 1)
          ESP_ERROR_CHECK(hid_class_request_set_protocol(hid_device_handle, HID_REPORT_PROTOCOL_REPORT));
#else
          ESP_ERROR_CHECK(hid_class_request_set_protocol(hid_device_handle, HID_REPORT_PROTOCOL_BOOT));
#endif
        } else {
          ESP_ERROR_CHECK(hid_class_request_set_protocol(hid_device_handle, HID_REPORT_PROTOCOL_BOOT));
          if (HID_PROTOCOL_KEYBOARD == dev_params.proto) {
            ESP_ERROR_CHECK(hid_class_request_set_idle(hid_device_handle, 0, 0));
          }
        }
      }
      ESP_ERROR_CHECK(hid_host_device_start(hid_device_handle));
      break;
    default:
      break;
  }
}

static void usb_lib_task(void *arg) {
  const usb_host_config_t host_config = {.skip_phy_setup = false, .intr_flags = ESP_INTR_FLAG_LEVEL1};
  ESP_ERROR_CHECK(usb_host_install(&host_config));
  xTaskNotifyGive((TaskHandle_t)arg);

  while (true) {
    uint32_t event_flags;
    usb_host_lib_handle_events(portMAX_DELAY, &event_flags);
    if (event_flags & USB_HOST_LIB_EVENT_FLAGS_NO_CLIENTS) {
      usb_host_device_free_all();
//      ESP_LOGI(TAG, "USB Event flags: NO_CLIENTS");
    }
    if (event_flags & USB_HOST_LIB_EVENT_FLAGS_ALL_FREE) {
//      ESP_LOGI(TAG, "USB Event flags: ALL_FREE");
    }
  }
}

void hid_host_task(void *pvParameters) {
  hid_host_event_queue_t evt_queue;
  hid_host_event_queue = xQueueCreate(10, sizeof(hid_host_event_queue_t));

  while (true) {
    if (xQueueReceive(hid_host_event_queue, &evt_queue, pdMS_TO_TICKS(50))) {
      hid_host_device_event(evt_queue.hid_device_handle, evt_queue.event, evt_queue.arg);
    }
  }
}

void hid_host_device_callback(hid_host_device_handle_t hid_device_handle, const hid_host_driver_event_t event, void *arg) {
  const hid_host_event_queue_t evt_queue = {.hid_device_handle = hid_device_handle, .event = event, .arg = arg};
  xQueueSend(hid_host_event_queue, &evt_queue, 0);
}

void app_main(void) {
  BaseType_t task_created;
//  ESP_LOGI(TAG, "HID Host example");
  task_created = xTaskCreatePinnedToCore(usb_lib_task, "usb_events", 4096, xTaskGetCurrentTaskHandle(), 2, NULL, 0);
  assert(task_created == pdTRUE);
  ulTaskNotifyTake(false, 1000);

  const hid_host_driver_config_t hid_host_driver_config = {
    .create_background_task = true,
    .task_priority = 5,
    .stack_size = 4096,
    .core_id = 0,
    .callback = hid_host_device_callback,
    .callback_arg = NULL
  };
  ESP_ERROR_CHECK(hid_host_install(&hid_host_driver_config));

  task_created = xTaskCreate(&hid_host_task, "hid_task", 4 * 1024, NULL, 2, NULL);
  assert(task_created == pdTRUE);
}

// -------------------- C64 timers/interrupts --------------------
void IRAM_ATTR handleInterrupt() {
  // Workaround: sometimes the interrupt triggers twice, check pin level
  if (!((GPIO.in >> C64_INT) & 1)) return;
  timerWrite(timerOnX, 0);
  timerAlarm(timerOnX, delayOnX, false, 0);
  timerWrite(timerOnY, 0);
  timerAlarm(timerOnY, delayOnY, false, 0);
}

void IRAM_ATTR turnOnPotX() {
  GPIO.out_w1ts = (1 << C64_POTX);
  timerWrite(timerOffX, 0);
  timerAlarm(timerOffX, delayOffX, false, 0);
}

void IRAM_ATTR turnOffPotX() { GPIO.out_w1tc = (1 << C64_POTX); }

void IRAM_ATTR turnOnPotY() {
  GPIO.out_w1ts = (1 << C64_POTY);
  timerWrite(timerOffY, 0);
  timerAlarm(timerOffY, delayOffY, false, 0);
}

void IRAM_ATTR turnOffPotY() { GPIO.out_w1tc = (1 << C64_POTY); }

void IRAM_ATTR turnOffJoyX() {
  digitalWrite(C64_LEFT, LOW);
  digitalWrite(C64_RIGHT, LOW);
  pinMode(C64_LEFT, INPUT);
  pinMode(C64_RIGHT, INPUT);
}

void IRAM_ATTR turnOffJoyY() {
  digitalWrite(C64_UP, LOW);
  digitalWrite(C64_DOWN, LOW);
  pinMode(C64_UP, INPUT);
  pinMode(C64_DOWN, INPUT);
}
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
void loop() {}

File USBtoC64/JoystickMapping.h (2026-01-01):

#pragma once
#include <Arduino.h>
#include <stdint.h>

// -------------------- Mapping mode selection --------------------
// JOY_MAP_LEARN  : use learning procedure + EEPROM mapping (handled by main sketch)
// JOY_MAP_CUSTOM : use hardcoded custom rules defined here

#define JOY_MAP_LEARN   0
#define JOY_MAP_CUSTOM  1

#ifndef JOY_MAPPING_MODE
  #define JOY_MAPPING_MODE JOY_MAP_LEARN
//  #define JOY_MAPPING_MODE JOY_MAP_CUSTOM
#endif

// -------------------- Custom mapping definitions --------------------
#if (JOY_MAPPING_MODE == JOY_MAP_CUSTOM)

enum JM_Op : uint8_t {
  JM_EQ = 0,      // (data[index] == value)
  JM_BITANY = 1   // ((data[index] & value) != 0)
};

enum JM_Func : uint8_t {
  JM_UP = 0,
  JM_UP_RIGHT,
  JM_RIGHT,
  JM_RIGHT_DOWN,
  JM_DOWN,
  JM_DOWN_LEFT,
  JM_LEFT,
  JM_LEFT_UP,
  JM_FIRE,
  JM_AUTOFIRE_ON,
  JM_AUTOFIRE_OFF,
  JM_AUTOLEFTRIGHT_ON,
  JM_AUTOLEFTRIGHT_OFF,

  // Extra mouse button for Amiga/Atari in joystick-as-mouse mode
  JM_BUTTON2
};

struct JM_Rule {
  uint8_t index;
  uint8_t value;
  JM_Op op;
  JM_Func func;
};

// Persistent states (custom mapping only)
static bool JM_autofire = false;
static bool JM_autoleftright = false;

// -------------------- Custom rules (JOYSTICK MODE) --------------------
// Edit this table for your controller.
// Example based on your snippet.
static const JM_Rule JM_JOY_RULES[] = {
  // Hat / D-pad directions on data[1]
  { 1, 0, JM_EQ, JM_UP },
  { 1, 1, JM_EQ, JM_UP_RIGHT },
  { 1, 2, JM_EQ, JM_RIGHT },
  { 1, 3, JM_EQ, JM_RIGHT_DOWN },
  { 1, 4, JM_EQ, JM_DOWN },
  { 1, 5, JM_EQ, JM_DOWN_LEFT },
  { 1, 6, JM_EQ, JM_LEFT },
  { 1, 7, JM_EQ, JM_LEFT_UP },

  // Extra "UP" source (example: data[8] == 8)
  { 8, 8, JM_EQ, JM_UP },

  // Fire sources (example: data[8] == 64 or 128 or 1)
  { 8, 64,  JM_EQ, JM_FIRE },
  { 8, 128, JM_EQ, JM_FIRE },
  { 8, 1,   JM_EQ, JM_FIRE },

  // Autofire toggles
  { 8, 16, JM_EQ, JM_AUTOFIRE_ON },
  { 8, 2,  JM_EQ, JM_AUTOFIRE_OFF },

  // Auto left/right toggles
  { 8, 32, JM_EQ, JM_AUTOLEFTRIGHT_ON },
  { 8, 4,  JM_EQ, JM_AUTOLEFTRIGHT_OFF }
};
static const size_t JM_JOY_RULES_COUNT = sizeof(JM_JOY_RULES) / sizeof(JM_JOY_RULES[0]);

// -------------------- Custom rules (JOYSTICK AS MOUSE MODE - C64 buttons) --------------------
// Typical: fire + "UP pin" used as right-click substitute on C64 setups.
static const JM_Rule JM_MOUSE_BTN_RULES_C64[] = {
  { 8, 64, JM_EQ, JM_FIRE },
  { 8, 1,  JM_EQ, JM_FIRE },
  { 8, 128, JM_EQ, JM_UP },        // Example: map to C64_UP in joystick-as-mouse mode
  { 8, 16, JM_EQ, JM_AUTOFIRE_ON },
  { 8, 2,  JM_EQ, JM_AUTOFIRE_OFF }
};
static const size_t JM_MOUSE_BTN_RULES_C64_COUNT = sizeof(JM_MOUSE_BTN_RULES_C64) / sizeof(JM_MOUSE_BTN_RULES_C64[0]);

// -------------------- Custom rules (JOYSTICK AS MOUSE MODE - Amiga/Atari buttons) --------------------
// Typical: fire + button2 (right mouse button line).
static const JM_Rule JM_MOUSE_BTN_RULES_A[] = {
  { 8, 64,  JM_EQ, JM_FIRE },
  { 8, 1,   JM_EQ, JM_FIRE },
  { 8, 128, JM_EQ, JM_BUTTON2 },   // Your custom firmware behavior
  { 8, 16,  JM_EQ, JM_AUTOFIRE_ON },
  { 8, 2,   JM_EQ, JM_AUTOFIRE_OFF }
};
static const size_t JM_MOUSE_BTN_RULES_A_COUNT = sizeof(JM_MOUSE_BTN_RULES_A) / sizeof(JM_MOUSE_BTN_RULES_A[0]);

// -------------------- Analog configuration --------------------

// Enable analog usage in joystick-as-mouse mode
#define JM_USE_ANALOG_MOUSE  1

// Axis sources (can be different for C64 vs Amiga/Atari if needed)
static const uint8_t JM_C64_MOUSE_X_INDEXES[] = { 2, 4 };
static const uint8_t JM_C64_MOUSE_Y_INDEXES[] = { 3, 5 };

static const uint8_t JM_A_MOUSE_X_INDEXES[]   = { 2, 4 };
static const uint8_t JM_A_MOUSE_Y_INDEXES[]   = { 3, 5 };

#define JM_ANALOG_CENTER      127
#define JM_ANALOG_DEAD_LOW     64
#define JM_ANALOG_DEAD_HIGH   190

// C64: delta added directly to delayOnX/delayOnY
#define JM_C64_ANALOG_DIV      3
#define JM_C64_Y_INVERT        1   // Keep C64 behavior (center - v)

// Amiga/Atari: convert analog to signed "steps"
#define JM_A_STEP_DIV          40  // Your custom firmware used /40
#define JM_A_Y_INVERT          0   // Your custom firmware used (v - center)

// Atari pulse scaling (your firmware used ~18.6 * PULSE_LENGTH / steps)
#define JM_ATARI_PULSE_SCALE   18.6f

static inline bool JM_match(const JM_Rule &r, const uint8_t *data, int length) {
  if ((int)r.index >= length) return false;
  uint8_t v = data[r.index];
  if (r.op == JM_EQ) return (v == r.value);
  return ((v & r.value) != 0);
}
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

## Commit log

2024-07-21 Added schematic
2024-07-21 fix schematic
2024-07-21 Add schematic
2024-07-26 Added the code for configuration of the joystick. Added images of the board. Added 3D drawings for an enclosure.
    [bottom.stl, top.stl]
2024-07-27 Fixed top case
    [top.stl]
2024-07-27 Minor fix
    [top.stl]
2024-07-29 Second release of the board (smaller)
    [USBtoC64-1.0.fzz, USBtoC64-2.0.fzz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]
2024-07-31 Cleaned repository and kept only version 2.1 with short boeard and cleaner circuit.
    [USBtoC64-1.0.fzz, USBtoC64-2.0.fzz, USBtoC64.fzz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]
2024-08-02 Added reset after calibration
    [USBtoC64.ino]
2024-08-06 Added smaller form factor board
    [USBtoC64-2.1.fzz, USBtoC64-3.0.fzz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]
2024-08-07 Fixed one version
    [USBtoC64-3.0.fzz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]
2024-08-12 Added a switch in preprocessor for PAL/NTSC
2024-08-17 addedd vendorId and deviceId to the configurator
2024-08-21 added version 3.0
    [USBtoC64-2.1.fzz, USBtoC64-3.0.fzz]
2024-08-22 Added UP button to 8bitdo configuration
2024-08-30 Added more buttons to configurator
2024-10-09 New board rev
    [USBtoC64-3.1.fzz]
2024-10-16 SMD Board
    [USBtoC64-4.0.fzz]
2024-11-13 Added AMIGA support
    [USBtoC64-2.1.fzz, USBtoC64-3.0.fzz, USBtoC64-3.1.fzz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]
2024-11-29 fix for latest board
    [USBtoC64.ino]
2024-12-02 fix inverted autodetection amiga atari
    [USBtoC64.ino]
2025-03-07 fix an issue with boot time detection
    [USBtoC64.ino]
2025-04-20 Added STL files for 3D case
    [bottom.stl, top.stl]
2025-07-09 3D case for THT version
    [bottom.3mf, top.3mf]
2025-12-08 Added new PCB for JLCPCB compatibility
    [USBtoC64-SMD-4.2.fzz]
2025-12-27 Simplify DE-9 connector instructions in README
    Removed unnecessary details about the DE-9 connector to streamline the instructions.
2025-12-27 Added BOM files for JLCPCB
    [BOM_SMD_PCB_42.xlsx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]
2026-01-01 fix Y direction
    [USBtoC64-SMD-4.2.fzz]
2026-01-01 fix and added down direction for middle button on C64
    [USBtoC64.ino]
2026-01-02 added 30 sec limit for computer switch
2026-01-09 Added experimenta firmware for Mouse Wheel
    [USBtoC64-SMD-4.1.fzz, bottom.3mf, bottom.stl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]
2026-01-09 Document experimental firmware for mouse wheel support
    Added section for experimental firmware with mouse wheel support for C64OS and AmigaOS, including setup instructions.
